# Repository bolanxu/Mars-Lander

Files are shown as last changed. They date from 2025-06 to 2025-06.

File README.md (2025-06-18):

# Mars Lander

https://youtu.be/TvxShnH4dns?si=FG6ILegN3fnswcwK

A Mars Lander control panel that simulates a landing on Mars. 
Built using simple physics, microcontrollers, and electronics.

This is is probably one of my most complex projects and it took me about a few months to build.
My first prototype was only a microcontroller development board with and 16x2 LCD screen (see /src/lcd)
And I made it in 7th grade, only about a year after I learned how to use the microcontroller.

I finish the 2nd upgraded prototype in December of 2024. I changed the LCD display to a full panel of 4 seven-segment displays, 8 leds, buttons, and potentiometers.
The code is in the /src/panel folder.

I used an microcontroller from the 8051 family, the STC125A60S2 developed by STC Microcontrollers. Compiled using SDCC.

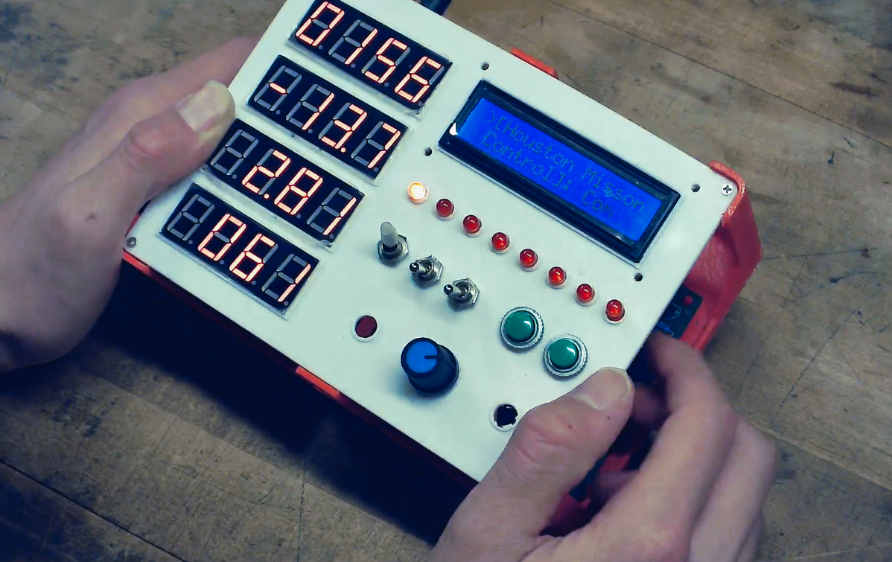
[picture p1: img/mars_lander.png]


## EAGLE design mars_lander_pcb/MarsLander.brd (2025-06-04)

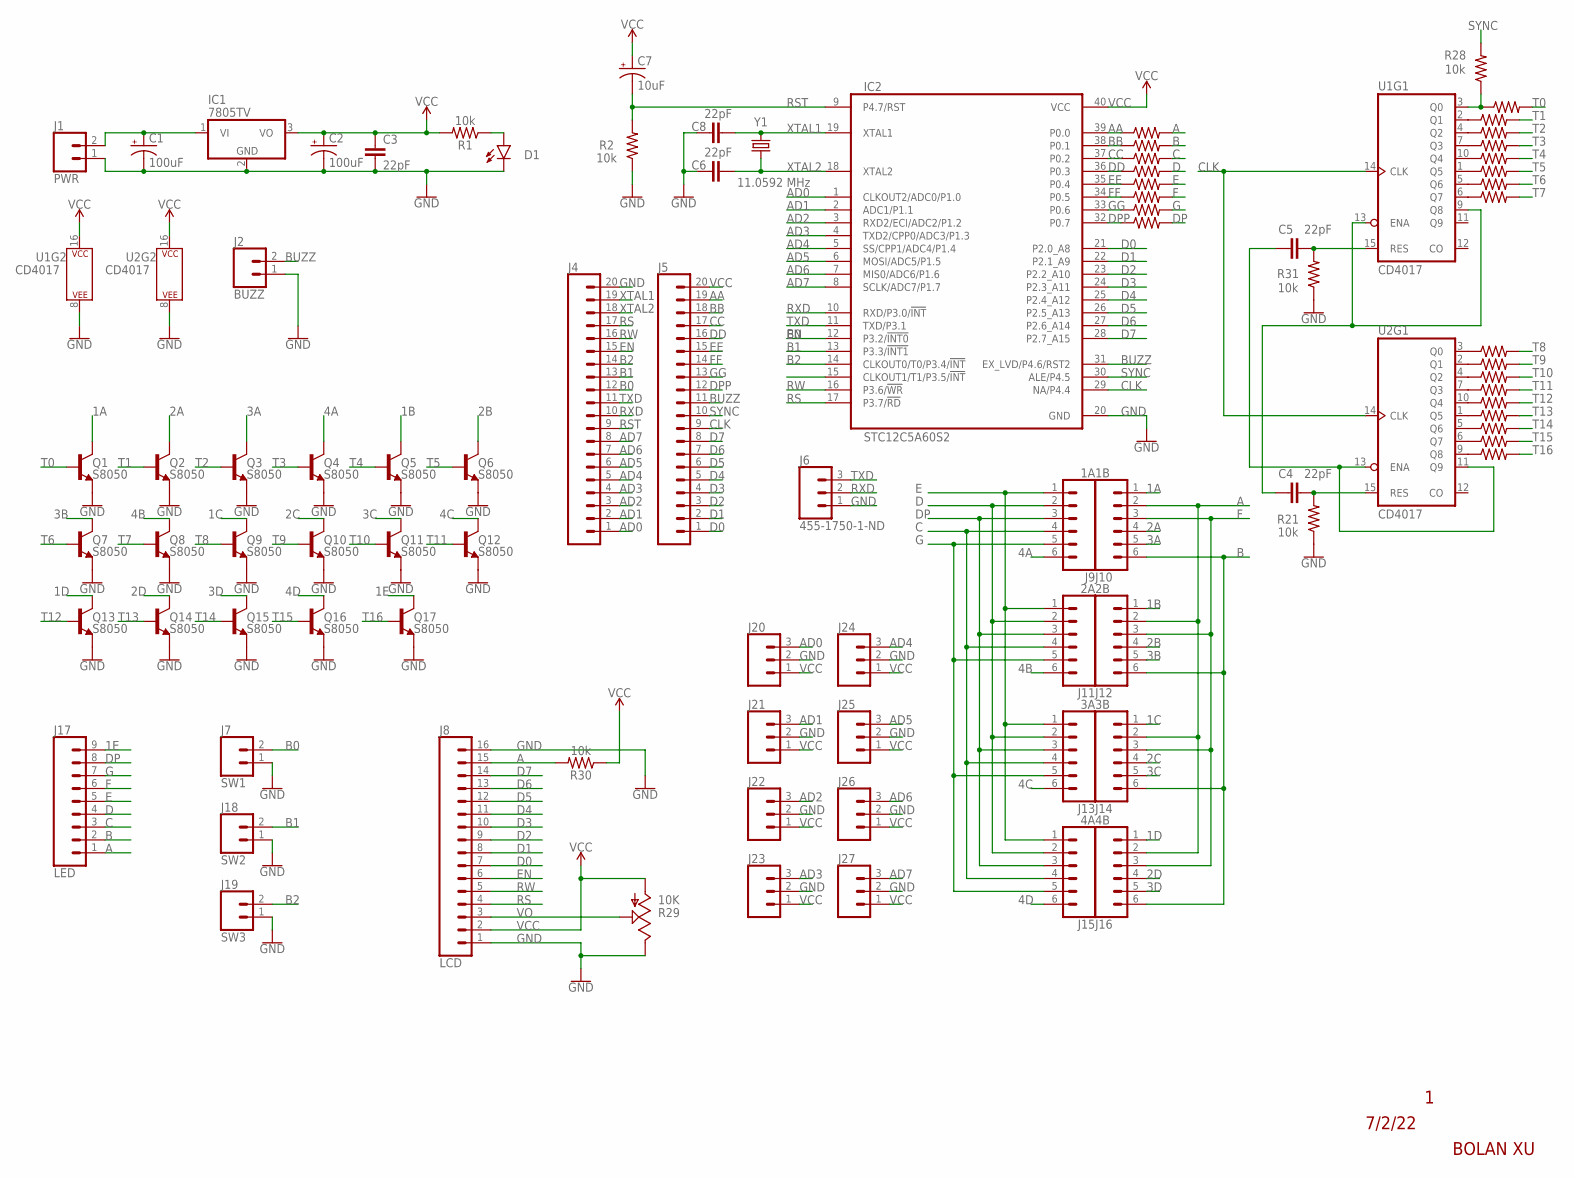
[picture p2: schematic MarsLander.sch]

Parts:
C1, C2: 100uF; CPOL-RADIAL-2.5MM-6.5MM
C3, C4, C5, C6, C8: 22pF; CAP-PTH-2.54
C7: 10uF; CPOL-RADIAL-2.5MM-5MM
D1: 3MM; LED_3MM
IC1: 7805TV; TO220V
IC2: STC12C5A60S2; DIL40
J1: PWR; 1X02
J2: BUZZ; 1X02
J4, J5: CONN_20; 1X20
J6, J20, J21, J22, J23, J24, J25, J26, J27: 455-1750-1-ND; 1X03
J7: SW1; 1X02
J8: LCD; 1X16
J9: 1A; 1X06
J10: 1B; 1X06
J11: 2A; 1X06
J12: 2B; 1X06
J13: 3A; 1X06
J14: 3B; 1X06
J15: 4A; 1X06
J16: 4B; 1X06
J17: LED; 1X09
J18: SW2; 1X02
J19: SW3; 1X02
Q1, Q2, Q3, Q4, Q5, Q6, Q7, Q8, Q9, Q10, Q11, Q12, Q13, Q14, Q15, Q16, Q17: S8050; TO-92
R1, R2, R3, R4, R5, R6, R7, R8, R9, R10, R11, R12, R13, R14, R15, R16, R17, R18, R19, R20, R21, R22, R23, R24, R25, R26, R27, R28, R30, R31, R33: 10k; AXIAL-0.3
R29: 10K; B25P
U1, U2: CD4017; DIP16
Y1: 11.0592 MHz; HC49U

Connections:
1A: J10.1, Q1.3 (C)
1B: J12.1, Q5.3 (C)
1C: J14.1, Q9.3 (C)
1D: J16.1, Q13.3 (C)
1E: J17.9, Q17.3 (C)
2A: J10.4, Q2.3 (C)
2B: J12.4, Q6.3 (C)
2C: J14.4, Q10.3 (C)
2D: J16.4, Q14.3 (C)
3A: J10.5, Q3.3 (C)
3B: J12.5, Q7.3 (C)
3C: J14.5, Q11.3 (C)
3D: J16.5, Q15.3 (C)
4A: J9.6, Q4.3 (C)
4B: J11.6, Q8.3 (C)
4C: J13.6, Q12.3 (C)
4D: J15.6, Q16.3 (C)
A: J8.15, J10.2, J12.2, J14.2, J16.2, J17.1, R19.P$2 (2), R30.P$2 (2)
AA: IC2.39 (P0.0), J5.19, R19.P$1 (1)
AD0: IC2.1 (CLKOUT2/ADC0/P1.0), J4.1, J20.3
AD1: IC2.2 (ADC1/P1.1), J4.2, J21.3
AD2: IC2.3 (RXD2/ECI/ADC2/P1.2), J4.3, J22.3
AD3: IC2.4 (TXD2/CPP0/ADC3/P1.3), J4.4, J23.3
AD4: IC2.5 (SS/CPP1/ADC4/P1.4), J4.5, J24.3
AD5: IC2.6 (MOSI/ADC5/P1.5), J4.6, J25.3
AD6: IC2.7 (MIS0/ADC6/P1.6), J4.7, J26.3
AD7: IC2.8 (SCLK/ADC7/P1.7), J4.8, J27.3
B: J10.6, J12.6, J14.6, J16.6, J17.2, R20.P$2 (2)
B0: IC2.12 (P3.2/!INT0), J4.12, J7.2
B1: IC2.13 (P3.3/!INT1), J4.13, J18.2
B2: IC2.14 (CLKOUT0/T0/P3.4/!INT), J4.14, J19.2
BB: IC2.38 (P0.1), J5.18, R20.P$1 (1)
BUZZ: IC2.31 (EX_LVD/P4.6/RST2), J2.2, J5.11
C: J9.4, J11.4, J13.4, J15.4, J17.3, R22.P$2 (2)
CC: IC2.37 (P0.2), J5.17, R22.P$1 (1)
CLK: IC2.29 (NA/P4.4), J5.9, U1.14 (CLK), U2.14 (CLK)
D: J9.2, J11.2, J13.2, J15.2, J17.4, R23.P$2 (2)
D0: IC2.21 (P2.0_A8), J5.1, J8.7
D1: IC2.22 (P2.1_A9), J5.2, J8.8
D2: IC2.23 (P2.2_A10), J5.3, J8.9
D3: IC2.24 (P2.3_A11), J5.4, J8.10
D4: IC2.25 (P2.4_A12), J5.5, J8.11
D5: IC2.26 (P2.5_A13), J5.6, J8.12
D6: IC2.27 (P2.6_A14), J5.7, J8.13
D7: IC2.28 (P2.7_A15), J5.8, J8.14
DD: IC2.36 (P0.3), J5.16, R23.P$1 (1)
DP: J9.3, J11.3, J13.3, J15.3, J17.8, R27.P$2 (2)
DPP: IC2.32 (P0.7), J5.12, R27.P$1 (1)
E: J9.1, J11.1, J13.1, J15.1, J17.5, R24.P$2 (2)
EE: IC2.35 (P0.4), J5.15, R24.P$1 (1)
EN: IC2.15 (CLKOUT1/T1/P3.5/!INT), J4.15, J8.6
F: J10.3, J12.3, J14.3, J16.3, J17.6, R25.P$2 (2)
FF: IC2.34 (P0.5), J5.14, R25.P$1 (1)
G: J9.5, J11.5, J13.5, J15.5, J17.7, R26.P$2 (2)
GG: IC2.33 (P0.6), J5.13, R26.P$1 (1)
GND: C1.2 (-), C2.2 (-), C3.2, C6.1, C8.1, D1.K (C), IC1.2 (GND), IC2.20 (GND), J1.1, J2.1, J4.20, J6.1, J7.1, J8.1, J8.16, J18.1, J19.1, J20.2, J21.2, J22.2, J23.2, J24.2, J25.2, J26.2, J27.2, Q1.1 (E), Q2.1 (E), Q3.1 (E), Q4.1 (E), Q5.1 (E), Q6.1 (E), Q7.1 (E), Q8.1 (E), Q9.1 (E), Q10.1 (E), Q11.1 (E), Q12.1 (E), Q13.1 (E), Q14.1 (E), Q15.1 (E), Q16.1 (E), Q17.1 (E), R2.P$1 (1), R21.P$1 (1), R29.E, R31.P$1 (1), U1.8 (P$V-), U2.8 (P$V-)
unnamed: C1.1 (+), IC1.1 (VI), J1.2
unnamed: C4.1, U1.9 (Q8), U1.13 (ENA)
unnamed: C5.1, U2.11 (Q9), U2.13 (ENA)
unnamed: C5.2, R31.P$2 (2), U1.15 (RES)
unnamed: C4.2, R21.P$2 (2), U2.15 (RES)
unnamed: R28.P$1 (1), R33.P$1 (1), U1.3 (Q0)
unnamed: R3.P$1 (1), U1.2 (Q1)
unnamed: R4.P$1 (1), U1.4 (Q2)
unnamed: R5.P$1 (1), U1.7 (Q3)
unnamed: R6.P$1 (1), U1.10 (Q4)
unnamed: R7.P$1 (1), U1.1 (Q5)
unnamed: R8.P$1 (1), U1.5 (Q6)
unnamed: R9.P$1 (1), U1.6 (Q7)
unnamed: R10.P$1 (1), U2.3 (Q0)
unnamed: R11.P$1 (1), U2.2 (Q1)
unnamed: R12.P$1 (1), U2.4 (Q2)
unnamed: D1.A, R1.P$1 (1)
unnamed: R13.P$1 (1), U2.7 (Q3)
unnamed: R14.P$1 (1), U2.10 (Q4)
unnamed: R15.P$1 (1), U2.1 (Q5)
unnamed: R16.P$1 (1), U2.5 (Q6)
unnamed: R17.P$1 (1), U2.6 (Q7)
unnamed: R18.P$1 (1), U2.9 (Q8)
RS: IC2.17 (P3.7/!RD), J4.17, J8.4
RST: C7.2 (-), IC2.9 (P4.7/RST), J4.9, R2.P$2 (2)
RW: IC2.16 (P3.6/!WR), J4.16, J8.5
RXD: IC2.10 (RXD/P3.0/!INT), J4.10, J6.2
SYNC: IC2.30 (ALE/P4.5), J5.10, R28.P$2 (2)
T0: Q1.2 (B), R33.P$2 (2)
T1: Q2.2 (B), R3.P$2 (2)
T2: Q3.2 (B), R4.P$2 (2)
T3: Q4.2 (B), R5.P$2 (2)
T4: Q5.2 (B), R6.P$2 (2)
T5: Q6.2 (B), R7.P$2 (2)
T6: Q7.2 (B), R8.P$2 (2)
T7: Q8.2 (B), R9.P$2 (2)
T8: Q9.2 (B), R10.P$2 (2)
T9: Q10.2 (B), R11.P$2 (2)
T10: Q11.2 (B), R12.P$2 (2)
T11: Q12.2 (B), R13.P$2 (2)
T12: Q13.2 (B), R14.P$2 (2)
T13: Q14.2 (B), R15.P$2 (2)
T14: Q15.2 (B), R16.P$2 (2)
T15: Q16.2 (B), R17.P$2 (2)
T16: Q17.2 (B), R18.P$2 (2)
TXD: IC2.11 (TXD/P3.1), J4.11, J6.3
VCC: C2.1 (+), C3.1, C7.1 (+), IC1.3 (VO), IC2.40 (VCC), J5.20, J8.2, J20.1, J21.1, J22.1, J23.1, J24.1, J25.1, J26.1, J27.1, R1.P$2 (2), R29.A, R30.P$1 (1), U1.16 (P$V+), U2.16 (P$V+)
VO: J8.3, R29.S
XTAL1: C8.2, IC2.19 (XTAL1), J4.19, Y1.2
XTAL2: C6.2, IC2.18 (XTAL2), J4.18, Y1.1

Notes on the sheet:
BOLAN XU
7/2/22

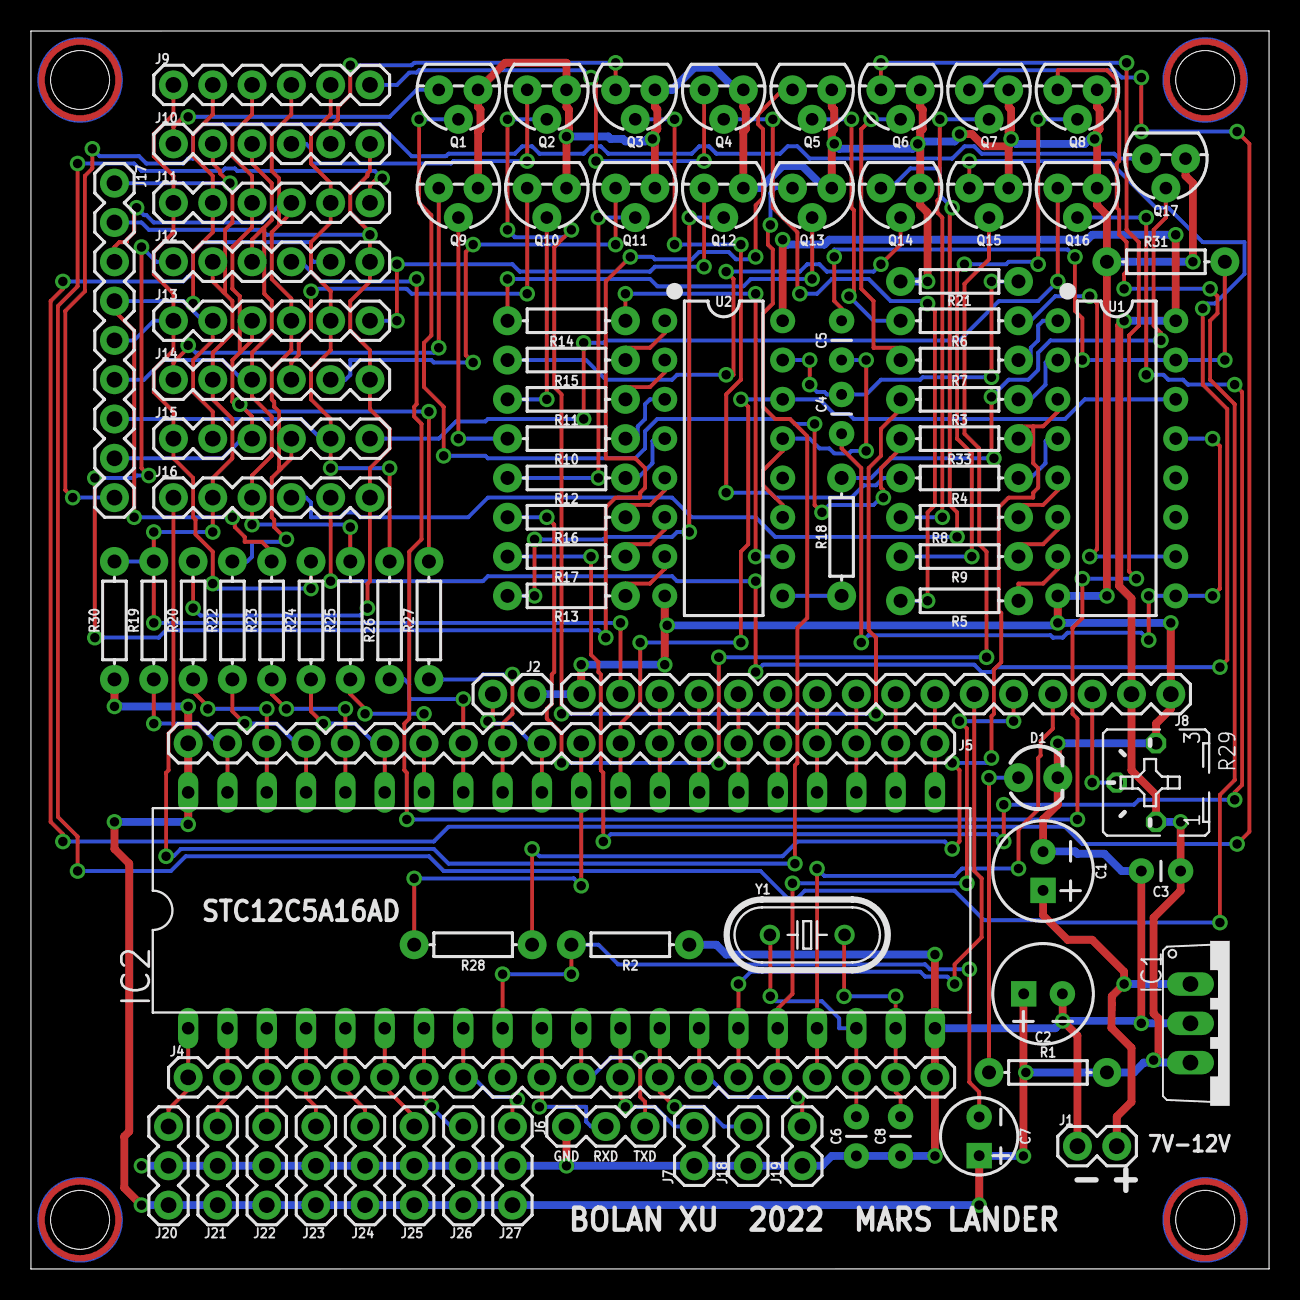
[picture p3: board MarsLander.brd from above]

Board: 2 copper layers, 80.0 x 80.0 mm, 89 parts (0 on the bottom side), 106 nets.

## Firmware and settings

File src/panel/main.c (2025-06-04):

#include <at89x52.h>
#include <stdlib.h>
//#include <string.h>

__sfr __at 0x94 P0M0;  
__sfr __at 0x93 P0M1;

__sfr __at 0x92 P1M0;  
__sfr __at 0x91 P1M1;

__sfr __at 0xB2 P3M0;  
__sfr __at 0xB1 P3M1;

__sfr __at 0x96 P2M0;  
__sfr __at 0x95 P2M1; 

__sfr __at 0xB4 P4M0;  
__sfr __at 0xB3 P4M1;

__sfr __at 0x8E AUXR;


__sfr __at 0xBC ADC_CONTR;        //ADC control register
__sfr __at 0xBD ADC_RES;          //ADC hight 8-bit result register
__sfr __at 0xBE ADC_LOW2;         //ADC low 2-bit result register
__sfr __at 0x9D P1ASF;            //P1 secondary function control register


 __sbit __at 0xAD EADC;
 

__sfr __at 0xB7 IPH;
__sfr __at 0xBB P4SW ; 
__sfr __at 0xC0 P4 ; //8 bitPort4          P4.7  P4.6  P4.5  P4.4  P4.3  P4.2  P4.1  P4.0       1111,1111
__sbit __at 0xC0 P4_0 ;
__sbit __at 0xC1 P4_1 ;
__sbit __at 0xC2 P4_2 ;
__sbit __at 0xC3 P4_3 ;
__sbit __at 0xC4 P4_4 ;
__sbit __at 0xC5 P4_5 ;
__sbit __at 0xC6 P4_6 ;
__sbit __at 0xC7 P4_7 ;

__sfr __at 0xD8 CCON ;           //PCA control register
__sbit __at 0xD8 CCF0 ;         //PCA module-0 interrupt flag
__sbit __at 0xD9 CCF1 ;        //PCA module-1 interrupt flag
__sbit __at 0xDE CR ;         //PCA timer run control bit
__sbit __at 0xDF CF ;         //PCA timer overflow flag
__sfr __at 0xD9 CMOD ;           //PCA mode register
__sfr __at 0xE9 CL ;           //PCA base timer LOW
__sfr __at 0xF9 CH ;           //PCA base timer HIGH
__sfr __at 0xDA CCAPM0 ;           //PCA module-0 mode register
__sfr __at 0xEA CCAP0L ;           //PCA module-0 capture register LOW
__sfr __at 0xFA CCAP0H ;           //PCA module-0 capture register HIGH
__sfr __at 0xDB CCAPM1 ;           //PCA module-1 mode registers
__sfr __at 0xEB CCAP1L ;           //PCA module-1 capture register LOW
__sfr __at 0xFB CCAP1H ;           //PCA module-1 capture register HIGH
__sfr __at 0xf2 PCAPWM0 ;
__sfr __at 0xf3 PCAPWM1 ;

#define FOSC    11059200L
#define T100Hz  (FOSC / 12 / 1000)

#define ADC_POWER 0x80 //ADC power control bit
#define ADC_FLAG 0x10 //ADC complete flag
#define ADC_START 0x08 //ADC start control bit
#define ADC_SPEEDLL 0x00 //540 clocks
#define ADC_SPEEDL 0x20 //360 clocks
#define ADC_SPEEDH 0x40 //180 clocks
#define ADC_SPEEDHH 0x60 //90 clocks

#define num0 0b00111111
#define num1 0b00000110
#define num2 0b01011011
#define num3 0b01001111
#define num4 0b01100110
#define num5 0b01101101
#define num6 0b01111101
#define num7 0b00000111
#define num8 0b01111111
#define num9 0b01101111
#define clear 0b00000000
#define negative 0b01000000

#define trigger P4_4


#define lcden P3_5
#define lcdrs P3_7
#define rw P3_6
#define B0 P3_2

__code unsigned char nums[12] = {num0,num1,num2,num3,num4,num5,num6,num7,num8,num9,clear,negative};


__code unsigned char win[] = ">You have succcessfully landed on the surface of Mars, research will start imeadiately.";
__code unsigned char lose[] = ">You have crashed on the surface of Mars. You are the lone survivor of the module. Good luck.";


__code unsigned char start1[] = ">[12:43PM Houston]: This is Houston, you have successfully detached from Command Module. Over >[12:43PM You]: Copy that. Awaiting manual engine control initiation. Over >[12:45PM You]: Come in Houston, engine control to manual. Initiating landing procedure >[12:46PM Houston]: Statistic report on Landing Module. Awaiting >[12:46PM You]:We have full control of the module. Fuel is at 99%. Ship integrity is at 100%. Height at 1005 meters above the surface. Over >[12:47PM Houston]: Copy that, you are go for landing. Good luck, this mission depends on you.";

__code unsigned char engine1[] = ">[Module Intercom] Commander, our engines are overheating. They are experiencing damage, engine thrust decreases by 10 percent.";

__code unsigned char turb1[] = ">[Houston Misson Control]: Come in Artemis. We have detected a level 2 sandstorm heading west at 83 m/s. Estimated impact time is unknown. Prepare imediately. I repeat prepare imediately!";
__code unsigned char turb2[] = ">[You]: Come in Houston. We have full impact, our acceleration is fluctuating rapidily";
__code unsigned char turb3[] = ">[You]: Come in Houston. We are out of the sandstorm. There seems to be only minor damages.";

__code unsigned char leak1[] = ">[Module Intercom] Commander, we have detected a fuel leak on the side of the module. Fuel is decreasing rapidly. There is no current way of fixing it";

__code unsigned char vel1[] = ">[Module Intercom] Commander, our velocity is too high. We are experiencing damage to the module.";

__code unsigned char disp[] = ">[Module Intercom] Commander, our display circuitry is encontering problems. The acceleration and fuel displays are broken.";
//unsigned char digits[4];


//unsigned char seconds;
//unsigned char minutes;

//int number = 0;

//int number3 = 0;



unsigned char velocityBit = 1;
__bit leakBit = 0;
unsigned int velTime = 0;



unsigned char digit1;
unsigned char digit2;
unsigned char digit3;
unsigned char digit4;

unsigned char digit1_1;
unsigned char digit1_2;
unsigned char digit1_3;
unsigned char digit1_4;
unsigned char digit1_5;

unsigned char digit2_1;
unsigned char digit2_2;
unsigned char digit2_3;
unsigned char digit2_4;
unsigned char digit2_5;
unsigned char digit2_6;

unsigned char digit3_1;
unsigned char digit3_2;
unsigned char digit3_3;
unsigned char digit3_4;


unsigned int rndNum = 100;

unsigned char w = 1;

unsigned int value;

unsigned int cnt = 0;


unsigned long runtime = 0;
//unsigned char runtime1 = 0;
unsigned long currentTime;
//unsigned char runtime1 = 0;

unsigned int i;

unsigned char enginebit = 0;
unsigned char stormBit = 0;
__bit bit1 = 0;
__bit bit2 = 1;
__bit bit3 = 1;
//unsigned char startbit;

float velocity = 0.0;
float in_thrust = 100000.0;
float thrust = 0.0;
float ship_thrust = 100000.0;
__code float ship_mass = 13000.0;
float height = 1000.0;
float gravity = 3.72;
float fuel = 8.2;
float delta_v = 0.0;
float delta_d = 0.0;
float delta_t = 1.0/20.0;
float a;
float delta_h;


unsigned int thrust_time = 0;


void Delay1ms()		//@11.0592MHz
{
	unsigned char i, j;
	i = 11;
	j = 190;
	do
	{
		while (--j);
	} while (--i);
}


void DelaySmalltest()		//@11.0592MHz
{
	unsigned char i, j;
	i = 2;
	j = 4;
	do
	{
		while (--j);
	} while (--i);
}


void delay(unsigned int time)
{
	unsigned int aa;
	for(aa=0;aa<time+1;aa++)
	{
		Delay1ms();
	}
}

void display(unsigned int num)
{
	P0 = nums[num];
}


void write_com(unsigned char com)
{
	lcdrs=0;
	rw=0;
	delay(5);
	P2=com;
	delay(5);
	lcden=1;
	delay(5);
	lcden=0;
}
 
void write_data(unsigned char data)
{
	lcdrs=1;
 	rw=0;
 	delay(5);
	P2=data;
	delay(5);
	lcden=1;
	delay(5);
	lcden=0;
}


void start()
{
	
	write_com(0x01);
	for (i=0;i<529;i++)
	{
		delay(50);
		if (i%32 == 0)
		{
			//delay(1000);
			write_com(0x01);
		}
		//else
		//{
		else if (i%16 == 0)
		{
			write_com(0x80+0x40);
		}
		//}
		if (start1[i]=='>')
		{
			write_com(0x01);
			CR=1;
		}
		write_data(start1[i]);
		
		if (i > 111)
		{
			//startbit = 0;
		}
		if (start1[i]==']')
		{
			delay(1000);
		}
	}
	delay(2000);
	write_com(0x01);
	//startbit = 1;
	i=0;
}


void Timer0Init(void)		//20ms@11.0592MHz
{
	AUXR = 0x00;		//Timer clock is 12T mode
	//TMOD = 0x01;		//Set timer work mode
	TL0 = 0x00;		//Initial timer value
	TH0 = 0x00;
	TF0 = 0;		//Clear TF0 flag
			//Timer0 start run
	ET0 = 1;
	EA = 1;
}

void Timer1Init(void)		//50ms@11.0592MHz
{
	//AUXR &= 0xBF;		//Timer clock is 12T mode
	TMOD = 0b00010001;		//Set timer work mode
	TL1 = 0x00;		//Initial timer value
	TH1 = 0x4C;		//Initial timer value
	TF1 = 0;		//Clear TF1 flag
	//TR1 = 1;		//Timer1 start run
	ET1 = 1;
	PT1= 1;
	IPH = 0x08;
}


void PcaInit(void)
{
	CCON = 0;                       //Initial PCA control register
    //CCAPM0 = 0b1001101;                                //PCA timer stop running
                                    //Clear CF flag
                                    //Clear all module interrupt flag
    CL = 0x00;                        //Reset PCA base timer
    CH = 0x00;
    CMOD = 0x00;                    //Set PCA timer clock source as Fosc/12
                                    //Disable PCA timer overflow interrupt
    value = T100Hz;
    CCAP0L = value;
    CCAP0H = value >> 8;            //Initial PCA module-0
    value += T100Hz;
    CCAPM0 = 0x49;                  //PCA module-0 work in 16-bit timer mode and enable PCA interrupt

    //CR = 1;                         //PCA timer start run
    EA = 1;
    //cnt = 0;
}


void InitADC( )
{
  P1ASF = 0b00000001; 
  ADC_RES = 0; //Clear previous result
  ADC_CONTR = ADC_POWER | ADC_SPEEDLL | ADC_START | 0;
  EADC = 1;
  delay(2); //ADC power-on delay and Start A/D conversion
}


void printLCD(char *ptr_stringPointer_u8)
{
	unsigned int charNum = 0;
	write_com(0x01);
    while((*ptr_stringPointer_u8)!=0)
  	{
    	charNum++;
    	if (charNum % 32 == 0)
    	{
    		write_com(0x01);
    	}
    	else if (charNum % 16 == 0)
    	{
    		write_com(0xc0);
    	}
        write_data(*ptr_stringPointer_u8++); // Loop through the string and display char by char
        delay(20);
    }
}

void init()
{
	lcden=0; //使能端为低电平
	write_com(0x38);
	/*显示模式设置  00111000  设置16*2显示  5*7点阵  8位数据接口*/
	write_com(0x0F);
	/*显示开关及光标设置   00001DCB
	D=1，开显示     D=0， 关显示
	C=1，显示光标   C=0，不显示光标
	B=1，光标闪烁   B=0，光标不闪烁*/
	write_com(0x06);//地址指针自动+1且光标+1，写字符屏幕不会移动
	write_com(0X01);
	write_com(0X80); 
}

void main()
{
	
	P4SW = 0x70;
	P4_6 = 1;
	P0 = 0x00;
	init(); 
	
	printLCD("hello");
	write_com(0xc0);
	printLCD("byebye");
	write_com(0x01);
	
	P0M0 = 0xFF;
	P0M1 = 0x00;
	P2M0 = 0xFF;
	P2M1 = 0x00;
	P3M0 = 0b11100000;
	P3M1 = 0x00;
	P4M0 = 0b01000000;
	P4M1 = 0b00100000;
	P4_4 = 0;
	P4_6=0;
	
	//w=0;
	P0 = 0xff;
	while(P4_5==0)
	{
		trigger = 1;
		trigger = 0;
		//delay(50);
	}
	for (i=0;i<18;i++)
	{
		trigger = 1;
		delay(50);
		trigger = 0;
		delay(50);
	}
	delay(500);
	P0 = 0x00;
	while(P4_5==0)
	{
		trigger = 1;
		trigger = 0;
		//delay(50);
	}
	//while(1);
	
	Timer0Init();
	Timer1Init();
	
	
	
	PcaInit();
	
	
	
	P0M0 = 0xFF;
	P0M1 = 0x00;
	P4M0 = 0b01000000;
	P4M1 = 0x00;
	P4_4 = 0;
	//CR = 1;
	//printLCD(win);
	start();
	
	
	
	TR0 = 1;
	TR1 = 1;
	
	InitADC();
	srand((ADC_RES+10)*10);
	rndNum = 10;
	while (1)
	{
		//number++;
		//number1++;
		//srand(1);
		if ((runtime % 2 == 0)&&(runtime > 20000))
			rndNum = rand();
		
		runtime++;
		if (runtime % 5000 == 0)
			srand((ADC_RES+10)*10);
		//if(runtime > )
		//{
		//	runtime1++;
		//	runtime = 0;
		//}
		
		if ((runtime == (currentTime + 10000)) && (bit3 == 0))
		{
			stormBit = 0;
			TR1 = 0;
			TR0 = 0;
			EADC = 0;
			P0 = 0x00;
			CR = 1;
			printLCD(turb3);
			//stormBit = 0;
			TR0 = 1;
			TR1 = 1;
			EADC = 1;
			bit3 = 1;
		}
		
		
		if ((rndNum*20) < 10)
		{
			if (bit1 == 0)
			{
				TR1 = 0;
				TR0 = 0;
				EADC = 0;
				P0 = 0x00;
				CR = 1;
				write_data(rndNum+0x30);
				delay(1000);
				write_com(0x01);
				printLCD(turb1);
				//stormBit = 0;
				TR0 = 1;
				TR1 = 1;
				EADC = 1; 
				bit1 = 1;
				bit2 = 0;
				currentTime = runtime;
			}
		}
		if ((runtime == (currentTime + 10000)) && (bit2 == 0))
		{
			
			TR1 = 0;
			TR0 = 0;
			EADC = 0;
			P0 = 0x00;
			CR = 1;
			printLCD(turb2);
			//stormBit = 0;
			TR0 = 1;
			TR1 = 1;
			EADC = 1;
			stormBit = 1;
			//bit1 = 1;
			bit2 = 1;
			bit3 = 0;
			currentTime = runtime;
		}
		if (thrust > 50000.0)
		{
			thrust_time++;
			if (thrust_time > 4000)
			{
				CR = 1;
				enginebit = 1;
				thrust_time = 0;
			}
		}
		else
		{
			thrust_time = 0;
		}
		
		if (velocity > 50.0 || velocity <-50.0)
		{
			velTime++;
			
			if (velocityBit == 1)
			{
				velocityBit = 0;
				TR1 = 0;
				TR0 = 0;
				EADC = 0;
				P0 = 0x00;
				CR = 1;
				printLCD(vel1);
				TR0 = 1;
				TR1 = 1;
				EADC = 1;
				velocityBit = 0;
			}
			if (velTime > 5000)
			{	
				
				if (leakBit == 0)
				{
					TR1 = 0;
					TR0 = 0;
					EADC = 0;
					P0 = 0x00;
					CR = 1;
					velTime = 0;
					printLCD(leak1);
					leakBit = 1;
					TR0 = 1;
					TR1 = 1;
					EADC = 1;
				}
			}
		}
		if (velocity < 48.0 && velocity > -48.0)
		{
			velocityBit = 1;
		}
		if (height < 1.0)
		{
			TR1 = 0;
			TR0 = 0;
			P0 = 0x00;
			if (velocity > -10.0)
			{
				TR1 = 0;
				TR0 = 0;
				EADC = 0;
				P0 = 0x00;
				CR = 1;
				printLCD(win);
				while(1);
			}
			else
			{
				TR1 = 0;
				TR0 = 0;
				EADC = 0;
				P0 = 0x00;
				CR = 1;
				printLCD(lose);
				while(1);
			}
		}
		
///////////////////////////////////////////////
		
		if (enginebit == 1)
		{
			TR1 = 0;
			TR0 = 0;
			EADC = 0;
			P0 = 0x00;
			CR = 1;
			printLCD(engine1);
			in_thrust = in_thrust*0.9;
			enginebit = 0;
			TR0 = 1;
			TR1 = 1;
			EADC = 1;
		}
		
		if (leakBit == 1)
		{
			fuel = fuel - 0.00002;
		}
		if (B0 == 0)
		{
			
			ship_thrust = in_thrust;
		}
		else
		{
			ship_thrust = in_thrust/2.0;
		}
//////////////////////////////////	
		
		//delay(5);
	}


}

void timer0Interrupt(void) __interrupt 1// __using 1
{
	
	TL0 = 0x80;		//Initial timer value
	TH0 = 0xFC;
	//Delay1mstest();
		//P0 = 0;
	//w = 0;
	//while(P4_5==0)
	//{
		//P4_4 = 0;
		//delay(5);
		//P4_4 = 1;
		//delay(5);
	
	//while(P3_2==1);
	//	while(P3_2==0);
		//while(P3_2==0);
	//	delay(5);
	//	while(P3_2==0);
	//write_com(0x01);
	
	if (w==0)
	{
		//write_data('0');
		while(P4_5==0)
		{
			P0 = 0x00;
			trigger = 0;
			trigger = 1;
			DelaySmalltest();
			trigger = 0;
			DelaySmalltest();
		}
		for (i=0;i<16;i++)
		{
			P0 = 0x00;
			trigger = 0;
			trigger = 1;
			DelaySmalltest();
			trigger = 0;
			DelaySmalltest();
		}
		display(digit1);
	}
	if (w==1)
	{
		//write_data('1');
		while(P4_5==0)
		{
			//P0 = 0xFF;
			trigger = 0;
			trigger = 1;
			//delay(200);
			trigger = 0;
			//delay(200);
		}
		
		//trigger = 0;
		//trigger = 1;
		//trigger = 0;
		display(digit2);
	}
	if (w==2)
	{
		//write_data('2');
		display(digit3);
	}
	if (w==3)
	{
		//write_data('3');
		display(digit4);
	}
//////////////////////////////////	
	if (w==4)
	{
		//write_data('4');
		display(digit1_1);
	}
	if (w==5)
	{
		//write_data('5');
		display(digit1_3);
		
	}
	if (w==6)
	{
		//write_data('6');
		display(digit1_4);
		P0_7 = 1;
	}
	if (w==7)
	{
		//write_data('7');
		display(digit1_5);
	}
//////////////////////////////////
	if (w==8)
	{
		//write_data('8');
		display(digit2_1);
	}
	if (w==9)
	{
		//write_data('9');
		display(digit2_4);
		P0_7 = 1;
	}
	if (w==10)
	{
		//write_data('1');
		//write_data('0');
		display(digit2_5);
	}
	if (w==11)
	{
		//write_data('1');
		///write_data('1');
		display(digit2_6);
	}
////////////////////////////////////
	
	if (w==12)
	{
		//write_data('1');
		//write_data('2');
		display(digit2_1);
	}
	if (w==13)
	{
		//write_data('1');
		//write_data('3');
		display(digit3_2);
	}
	if (w==14)
	{
		//write_data('1');
		//write_data('4');
		display(digit3_3);
	}
	if (w==15)
	{
		//write_data('1');
		//write_data('5');
		display(digit3_4);
		//display(8);
	}
	if (w == 16)
	{
		///write_data('1');
		//write_data('6');
		P0 = 0xFF;
	}
	if (w<17)
	{
		w++;
	}
	if (w>16)
	{
		w=0;
	}
	
	trigger = 0;
	trigger = 1;
	DelaySmalltest();
	trigger = 0;
}

void adc_isr( ) __interrupt 5 __using 1
{
  ADC_CONTR &= !ADC_FLAG; //Clear ADC interrupt flag
  //SendData(ch); //Show Channel NO.
  //SendData(); //Get ADC high 8-bit result and Send to UART
  if (fuel < 0.1)
	thrust = 0;
  else 
  {
  
	thrust = (ADC_RES - 0) * (ship_thrust - 0) / (255 - 0);
	
	//thrust = in_thrust;
  }
  
  //ch = 0; //switch to next channel
  ADC_CONTR = ADC_POWER | ADC_SPEEDLL | ADC_START | 0;
  
  
  
}

void timer1interrupt(void) __interrupt 3
{
	unsigned int b, int_input;
	int number1 = 0;
	int number2 = 0;	
	
	TL1 = 0x00;		//Initial timer value
	TH1 = 0x4C;		
	
	if (stormBit == 1)
	{
		EADC = 0;
		//velocity = -5.0;
		thrust = 0;
		//a = 5.67;
		a = ((float)rndNum) / 100.0;
	}
	else
		a = (1.2*thrust / (ship_mass + fuel) - gravity);
	delta_v = delta_t * a;
	velocity = velocity + delta_v;
	delta_h = velocity * delta_t;
	height = height + delta_h;
	if (fuel < 0.1)
		fuel = 0.0;
	else
		fuel = fuel-(thrust/20000000);
	
	
		if (velocity < 0)
		{
			digit1_1 = 11;
			number1 = velocity*-10;
		}
		else 
		{
			digit1_1 = 10;
			number1 = velocity*10;
		}
		if (a < 0)
		{
			digit2_1 = 11;
			number2 = a*-100;
		}
		else 
		{
			digit2_1 = 10;
			number2 = a*100;
		}
		//number = height;
		
		int_input = (int) height;
	
		digit4 = int_input % 10;
		b = int_input / 10;
		
		digit3 = b % 10;
		b = b / 10;
		
		digit2 = b % 10;
		b = b / 10;
		
		digit1 = (int)b;
		
		//number1 = number1;
		int_input = (int) (number1);
	
		digit1_5= int_input % 10;
		b = int_input / 10;
		
		digit1_4 = b % 10;
		b = b / 10;
		
		digit1_3 = b % 10;
		b = b / 10;
		
		digit1_2 = b % 10;
		b = b / 10;
		
		//digit1_1 = b % 10;
		
		
		int_input = (int) number2;
	
		digit2_6= int_input % 10;
		b = int_input / 10;
		
		digit2_5 = b % 10;
		b = b / 10;
		
		digit2_4 = b % 10;
		b = b / 10;
		
		digit2_3 = b % 10;
		b = b / 10;
		
		digit2_2 = b % 10;
		b = b / 10;
		
		//digit2_1 = b % 10;
		
		
		//number3 = ;
		int_input = (int) ((fuel/8.2)*100);
		
		digit3_4 = int_input % 10;
		b = int_input / 10;
		
		digit3_3 = b % 10;
		b = b / 10;
		
		digit3_2 = b % 10;
		b = b / 10;
		
		digit3_1 = b % 10;
}


void PCA_isr() __interrupt 7
{
	
    CCF0 = 0;                       //Clear interrupt flag
    CCAP0L = value;
    CCAP0H = value >> 8;            //Update compare value
    value += T100Hz;
    cnt++;
    
	if (cnt<300)
	{
        P4_6 = !P4_6;         //Flash once per second
	}
	else if (cnt<600)
	{
        P4_6 = P4_6;        
	}
	else if (cnt<900)
	{
        P4_6 = !P4_6;         //Flash once per second
	}
	else if (cnt<1200)
	{
        P4_6 = P4_6;         
	}
	else if (cnt<1500)
	{
        P4_6 = !P4_6;         //Flash once per second
	}
	else if (cnt<1800)
	{
        P4_6 = P4_6;         
	}
	else 
	{
		cnt = 0;
		CR = 0;
	}
}

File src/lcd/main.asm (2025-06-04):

;--------------------------------------------------------
; File Created by SDCC : free open source ANSI-C Compiler
; Version 3.5.0 #9253 (Apr  3 2018) (Linux)
; This file was generated Sat Mar 11 13:47:00 2023
;--------------------------------------------------------
	.module main
	.optsdcc -mmcs51 --model-small
	
;--------------------------------------------------------
; Public variables in this module
;--------------------------------------------------------
	.globl _emb2
	.globl _emb1
	.globl _em3
	.globl _em2
	.globl _em1
	.globl _leak3
	.globl _leak2
	.globl _leak1
	.globl _turb3
	.globl _turb2
	.globl _turb1
	.globl _enginep5
	.globl _enginep4
	.globl _enginep3
	.globl _enginep2
	.globl _enginep1
	.globl _start11
	.globl _start10
	.globl _start9
	.globl _start8
	.globl _start7
	.globl _start6
	.globl _start5
	.globl _start4
	.globl _start3
	.globl _start2
	.globl _start1
	.globl _gameover
	.globl _lose
	.globl _win
	.globl _timer1
	.globl _INT0_INT
	.globl _timer0
	.globl _main
	.globl _enginepower
	.globl _turb
	.globl _fuelleak
	.globl _start
	.globl _init
	.globl _write_data
	.globl _write_com
	.globl _delay
	.globl _Timer0Init
	.globl _CY
	.globl _AC
	.globl _F0
	.globl _RS1
	.globl _RS0
	.globl _OV
	.globl _FL
	.globl _P
	.globl _TF2
	.globl _EXF2
	.globl _RCLK
	.globl _TCLK
	.globl _EXEN2
	.globl _TR2
	.globl _C_T2
	.globl _CP_RL2
	.globl _T2CON_7
	.globl _T2CON_6
	.globl _T2CON_5
	.globl _T2CON_4
	.globl _T2CON_3
	.globl _T2CON_2
	.globl _T2CON_1
	.globl _T2CON_0
	.globl _PT2
	.globl _PS
	.globl _PT1
	.globl _PX1
	.globl _PT0
	.globl _PX0
	.globl _RD
	.globl _WR
	.globl _T1
	.globl _T0
	.globl _INT1
	.globl _INT0
	.globl _TXD
	.globl _RXD
	.globl _P3_7
	.globl _P3_6
	.globl _P3_5
	.globl _P3_4
	.globl _P3_3
	.globl _P3_2
	.globl _P3_1
	.globl _P3_0
	.globl _EA
	.globl _ET2
	.globl _ES
	.globl _ET1
	.globl _EX1
	.globl _ET0
	.globl _EX0
	.globl _P2_7
	.globl _P2_6
	.globl _P2_5
	.globl _P2_4
	.globl _P2_3
	.globl _P2_2
	.globl _P2_1
	.globl _P2_0
	.globl _SM0
	.globl _SM1
	.globl _SM2
	.globl _REN
	.globl _TB8
	.globl _RB8
	.globl _TI
	.globl _RI
	.globl _T2EX
	.globl _T2
	.globl _P1_7
	.globl _P1_6
	.globl _P1_5
	.globl _P1_4
	.globl _P1_3
	.globl _P1_2
	.globl _P1_1
	.globl _P1_0
	.globl _TF1
	.globl _TR1
	.globl _TF0
	.globl _TR0
	.globl _IE1
	.globl _IT1
	.globl _IE0
	.globl _IT0
	.globl _P0_7
	.globl _P0_6
	.globl _P0_5
	.globl _P0_4
	.globl _P0_3
	.globl _P0_2
	.globl _P0_1
	.globl _P0_0
	.globl _B
	.globl _A
	.globl _ACC
	.globl _PSW
	.globl _TH2
	.globl _TL2
	.globl _RCAP2H
	.globl _RCAP2L
	.globl _T2MOD
	.globl _T2CON
	.globl _IP
	.globl _P3
	.globl _IE
	.globl _P2
	.globl _SBUF
	.globl _SCON
	.globl _P1
	.globl _TH1
	.globl _TH0
	.globl _TL1
	.globl _TL0
	.globl _TMOD
	.globl _TCON
	.globl _PCON
	.globl _DPH
	.globl _DPL
	.globl _SP
	.globl _P0
	.globl _l
	.globl _s
	.globl _n
	.globl _x
	.globl _digit4
	.globl _digit3
	.globl _digit2
	.globl _digit1
	.globl _delta_h
	.globl _a
	.globl _delta_t
	.globl _delta_d
	.globl _delta_v
	.globl _fuel
	.globl _gravity
	.globl _height
	.globl _ship_mass
	.globl _ship_thrust
	.globl _thrust
	.globl _velocity
	.globl _num
	.globl _digit
	.globl _sign
	.globl _displaynum
;--------------------------------------------------------
; special function registers
;--------------------------------------------------------
	.area RSEG    (ABS,DATA)
	.org 0x0000
_P0	=	0x0080
_SP	=	0x0081
_DPL	=	0x0082
_DPH	=	0x0083
_PCON	=	0x0087
_TCON	=	0x0088
_TMOD	=	0x0089
_TL0	=	0x008a
_TL1	=	0x008b
_TH0	=	0x008c
_TH1	=	0x008d
_P1	=	0x0090
_SCON	=	0x0098
_SBUF	=	0x0099
_P2	=	0x00a0
_IE	=	0x00a8
_P3	=	0x00b0
_IP	=	0x00b8
_T2CON	=	0x00c8
_T2MOD	=	0x00c9
_RCAP2L	=	0x00ca
_RCAP2H	=	0x00cb
_TL2	=	0x00cc
_TH2	=	0x00cd
_PSW	=	0x00d0
_ACC	=	0x00e0
_A	=	0x00e0
_B	=	0x00f0
;--------------------------------------------------------
; special function bits
;--------------------------------------------------------
	.area RSEG    (ABS,DATA)
	.org 0x0000
_P0_0	=	0x0080
_P0_1	=	0x0081
_P0_2	=	0x0082
_P0_3	=	0x0083
_P0_4	=	0x0084
_P0_5	=	0x0085
_P0_6	=	0x0086
_P0_7	=	0x0087
_IT0	=	0x0088
_IE0	=	0x0089
_IT1	=	0x008a
_IE1	=	0x008b
_TR0	=	0x008c
_TF0	=	0x008d
_TR1	=	0x008e
_TF1	=	0x008f
_P1_0	=	0x0090
_P1_1	=	0x0091
_P1_2	=	0x0092
_P1_3	=	0x0093
_P1_4	=	0x0094
_P1_5	=	0x0095
_P1_6	=	0x0096
_P1_7	=	0x0097
_T2	=	0x0090
_T2EX	=	0x0091
_RI	=	0x0098
_TI	=	0x0099
_RB8	=	0x009a
_TB8	=	0x009b
_REN	=	0x009c
_SM2	=	0x009d
_SM1	=	0x009e
_SM0	=	0x009f
_P2_0	=	0x00a0
_P2_1	=	0x00a1
_P2_2	=	0x00a2
_P2_3	=	0x00a3
_P2_4	=	0x00a4
_P2_5	=	0x00a5
_P2_6	=	0x00a6
_P2_7	=	0x00a7
_EX0	=	0x00a8
_ET0	=	0x00a9
_EX1	=	0x00aa
_ET1	=	0x00ab
_ES	=	0x00ac
_ET2	=	0x00ad
_EA	=	0x00af
_P3_0	=	0x00b0
_P3_1	=	0x00b1
_P3_2	=	0x00b2
_P3_3	=	0x00b3
_P3_4	=	0x00b4
_P3_5	=	0x00b5
_P3_6	=	0x00b6
_P3_7	=	0x00b7
_RXD	=	0x00b0
_TXD	=	0x00b1
_INT0	=	0x00b2
_INT1	=	0x00b3
_T0	=	0x00b4
_T1	=	0x00b5
_WR	=	0x00b6
_RD	=	0x00b7
_PX0	=	0x00b8
_PT0	=	0x00b9
_PX1	=	0x00ba
_PT1	=	0x00bb
_PS	=	0x00bc
_PT2	=	0x00bd
_T2CON_0	=	0x00c8
_T2CON_1	=	0x00c9
_T2CON_2	=	0x00ca
_T2CON_3	=	0x00cb
_T2CON_4	=	0x00cc
_T2CON_5	=	0x00cd
_T2CON_6	=	0x00ce
_T2CON_7	=	0x00cf
_CP_RL2	=	0x00c8
_C_T2	=	0x00c9
_TR2	=	0x00ca
_EXEN2	=	0x00cb
_TCLK	=	0x00cc
_RCLK	=	0x00cd
_EXF2	=	0x00ce
_TF2	=	0x00cf
_P	=	0x00d0
_FL	=	0x00d1
_OV	=	0x00d2
_RS0	=	0x00d3
_RS1	=	0x00d4
_F0	=	0x00d5
_AC	=	0x00d6
_CY	=	0x00d7
;--------------------------------------------------------
; overlayable register banks
;--------------------------------------------------------
	.area REG_BANK_0	(REL,OVR,DATA)
	.ds 8
;--------------------------------------------------------
; overlayable bit register bank
;--------------------------------------------------------
	.area BIT_BANK	(REL,OVR,DATA)
bits:
	.ds 1
	b0 = bits[0]
	b1 = bits[1]
	b2 = bits[2]
	b3 = bits[3]
	b4 = bits[4]
	b5 = bits[5]
	b6 = bits[6]
	b7 = bits[7]
;--------------------------------------------------------
; internal ram data
;--------------------------------------------------------
	.area DSEG    (DATA)
_num::
	.ds 1
_velocity::
	.ds 4
_thrust::
	.ds 4
_ship_thrust::
	.ds 4
_ship_mass::
	.ds 4
_height::
	.ds 4
_gravity::
	.ds 4
_fuel::
	.ds 4
_delta_v::
	.ds 4
_delta_d::
	.ds 4
_delta_t::
	.ds 4
_a::
	.ds 4
_delta_h::
	.ds 4
_digit1::
	.ds 1
_digit2::
	.ds 1
_digit3::
	.ds 1
_digit4::
	.ds 1
_x::
	.ds 2
_n::
	.ds 2
_s::
	.ds 2
;--------------------------------------------------------
; overlayable items in internal ram 
;--------------------------------------------------------
	.area	OSEG    (OVR,DATA)
;--------------------------------------------------------
; Stack segment in internal ram 
;--------------------------------------------------------
	.area	SSEG
__start__stack:
	.ds	1
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

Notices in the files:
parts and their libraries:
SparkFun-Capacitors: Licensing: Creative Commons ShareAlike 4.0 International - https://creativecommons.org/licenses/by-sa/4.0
